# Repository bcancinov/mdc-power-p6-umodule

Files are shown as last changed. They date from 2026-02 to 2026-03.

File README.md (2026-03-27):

# mdc-power-p6-umodule
Modular Detector Controller Power 6V DC-DC uModule Mezzanine Module

## Overview
12V input to 6V output DC-DC module, 3A nominal output, used as one of the `mdc-power-*` bias rails.
Designed for 2.0 MHz sync operation.
Mezzanine module.

## Power Stage
- Controller: `LTM4653` (`U1`)
  - Integrated µModule regulator including controller, MOSFETs, inductor, and support components.
  - Low-EMI µModule architecture suited for sensitive instrumentation rails.
  - EN55022B compliant regulator family (meets Class B EMI limits for conducted and radiated emissions).
  - Wide input range suitable for 12V systems.
  - Constant-frequency current-mode control.
  - Power good indicator and programmable soft-start.
  - External sync capability.

## Files
- Schematic: `power_p6_umodule.pdf`
- Simulation: `sim/` (LTspice and LTpowerCAD files used for loop and transient checks)

## Board Dimensions
- 44.8 mm x 41.5 mm

## Board Stackup
- 4-layer PCB

## CAD
- Designed using KiCad 9.

## Interface
- Control pins: `EN` (enable) and `PG` / `~PGOOD` (power good).
- Connector: `LSHM-140-04.0-L-DV-A-N-K-TR` (Samtec LSHM series) mezzanine for power and control signals.
  - Common pinout is shared across the 16V, -16V, 6V, and 3.3V variants.
  - Unused output rails are tied to GND on the specific module variant.

## Images
Layout:
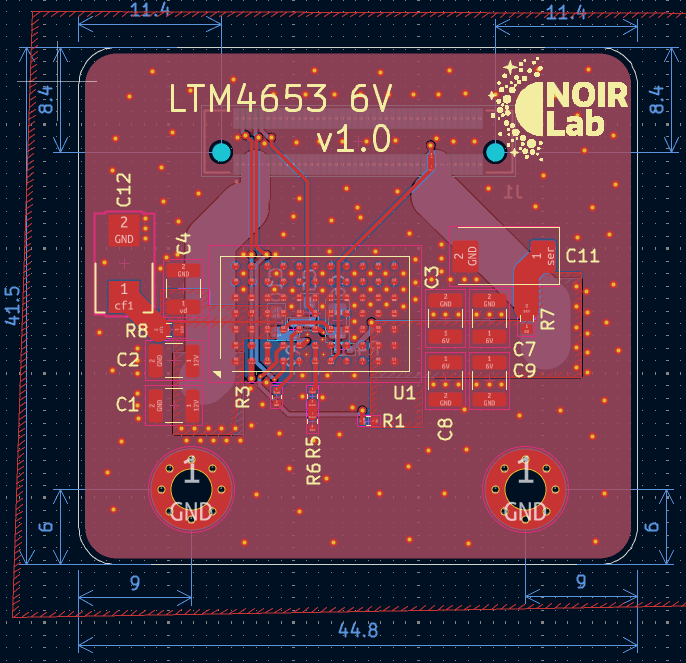
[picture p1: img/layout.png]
Layout


3D view:
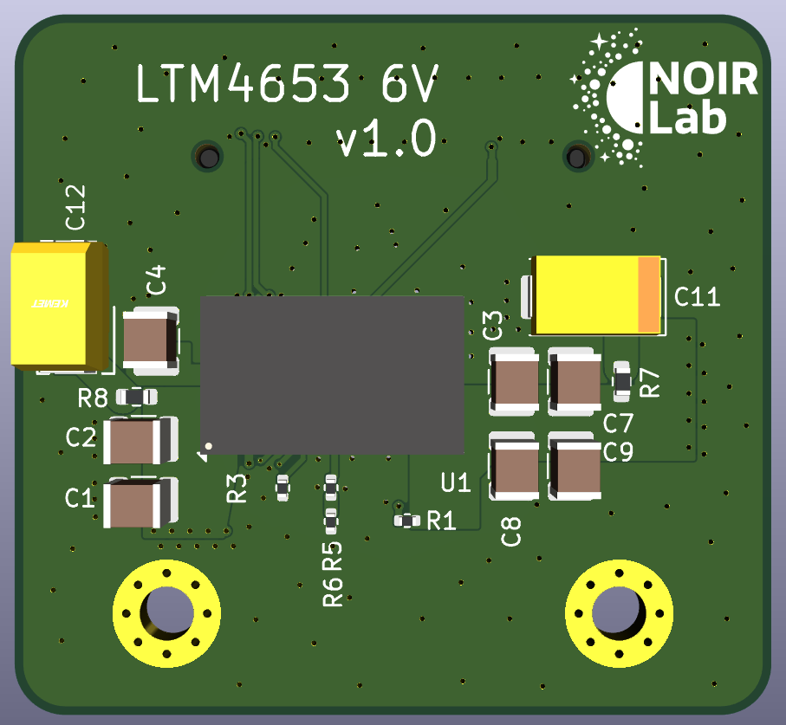
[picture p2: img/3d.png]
3D view


## License

This hardware design is licensed under the **Creative Commons Attribution-NonCommercial-ShareAlike 4.0 International License** (CC BY-NC-SA 4.0).

You are free to download, modify, and build upon this design for your own research or personal use, provided you give appropriate credit and share your modifications under the exact same license. **Commercial manufacturing or use of these designs is strictly prohibited without explicit permission.**

To view a copy of this license, visit [http://creativecommons.org/licenses/by-nc-sa/4.0/](http://creativecommons.org/licenses/by-nc-sa/4.0/) or see the `LICENSE` file in this repository.

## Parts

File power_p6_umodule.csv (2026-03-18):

Reference | Qty | M | MPN | Description
C1,C2,C4 | 3 | Murata | GRM32ER71K475KE14L | 4.7 µF ±10% 80V Ceramic Capacitor X7R 1210 (3225 Metric)
C3,C7,C8,C9 | 4 | TAIYO YUDEN | TMK325ABJ476MM-P | 47 µF ±20% 25V Ceramic Capacitor X5R 1210 (3225 Metric)
C5 | 1 | Murata | GRT1885C1E103FA02D | 10000 pF ±1% 25V Ceramic Capacitor C0G, NP0 0603 (1608 Metric)
C6 | 1 | Murata | GCM21BR71H105KA03L | 1 µF ±10% 50V Ceramic Capacitor X7R 0805 (2012 Metric)
C10 | 1 | Murata | GCM1885C2A100FA16D | 10 pF ±1% 100V Ceramic Capacitor C0G, NP0 0603 (1608 Metric)
C11 | 1 | KEMET | T521V226M025ATE040 | 22 µF Molded Tantalum Polymer Capacitor 25 V 2917 (7343 Metric) 40mOhm @ 100kHz
C12 | 1 | Kemet | T521X107M025ATE060 | 100 µF Molded Tantalum Polymer Capacitor 25 V 2917 (7343 Metric) 60mOhm @ 100kHz
H1,H2,NT1 | 3 |  |  | Mounting Hole with connection,Net tie, 2 pins
J1 | 1 | Samtec | LSHM-140-04.0-L-DV-A-N-K-TR | 80 Position Connector Self Mating, Non-Gendered, Hermaphroditic Surface Mount Gold
R1 | 1 | Vishay | CRCW040244K2FKED | 44.2 kOhms ±1% 0.1W, 1/10W Chip Resistor 0402 (1005 Metric) Automotive AEC-Q200 Thick Film
R2 | 1 | Vishay | CRCW04028K87FKED | 8.87 kOhms ±1% 0.1W, 1/10W Chip Resistor 0402 (1005 Metric) Automotive AEC-Q200 Thick Film
R3 | 1 | Vishay | CRCW040261K9FKED | Resistor, small symbol
R4 | 1 | Vishay | CRCW040224R0FKED | 24 Ohms ±1% 0.1W, 1/10W Chip Resistor 0402 (1005 Metric) Automotive AEC-Q200 Thick Film
R5 | 1 | Yageo | MCS04020C1203FE000 | 120 kOhms ±1% 0.063W, 1/16W Chip Resistor 0402 (1005 Metric) Anti-Sulfur Thin Film
R7,R8 | 2 | Vishay | RCWE0603R500FKEA | 500 mOhms ±1% 0.2W, 1/5W Chip Resistor 0603 (1608 Metric) Automotive AEC-Q200, Current Sense, Moisture Resistant Thick Film
U1 | 1 | Analog | LTM4653EY#PBF | Non-Isolated PoL Module DC DC Converter 1 Output 0.5 ~ 54.5V 4A 3.1V - 58V Input

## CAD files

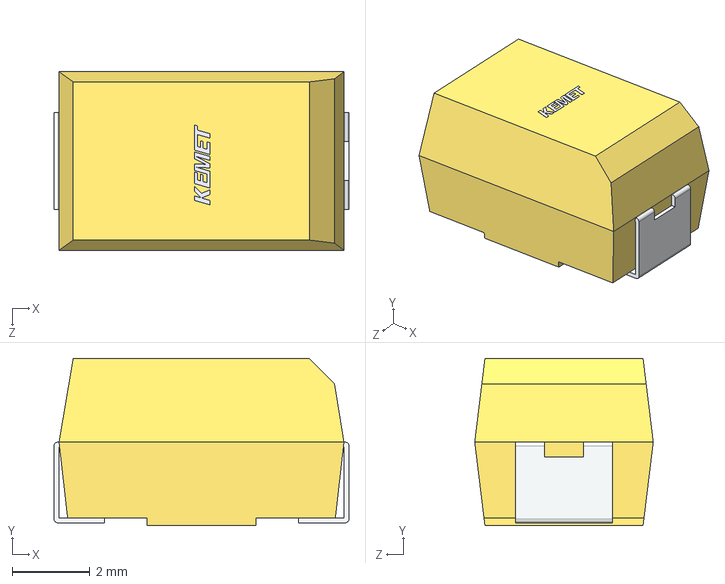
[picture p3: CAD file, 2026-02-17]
step/T521X.step
7.60 x 4.30 x 4.60 mm

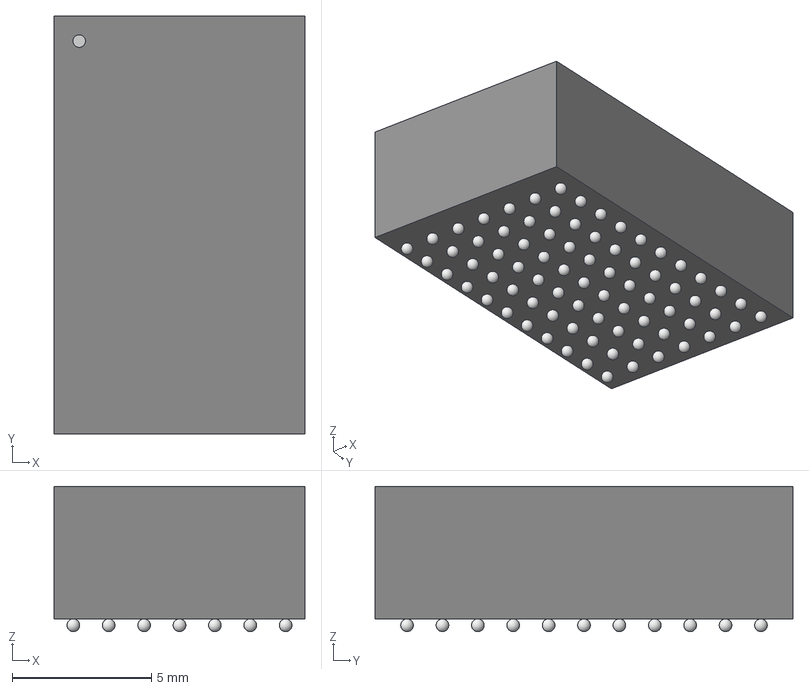
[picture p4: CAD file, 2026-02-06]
step/BGA77.step
9.00 x 15.0 x 5.21 mm

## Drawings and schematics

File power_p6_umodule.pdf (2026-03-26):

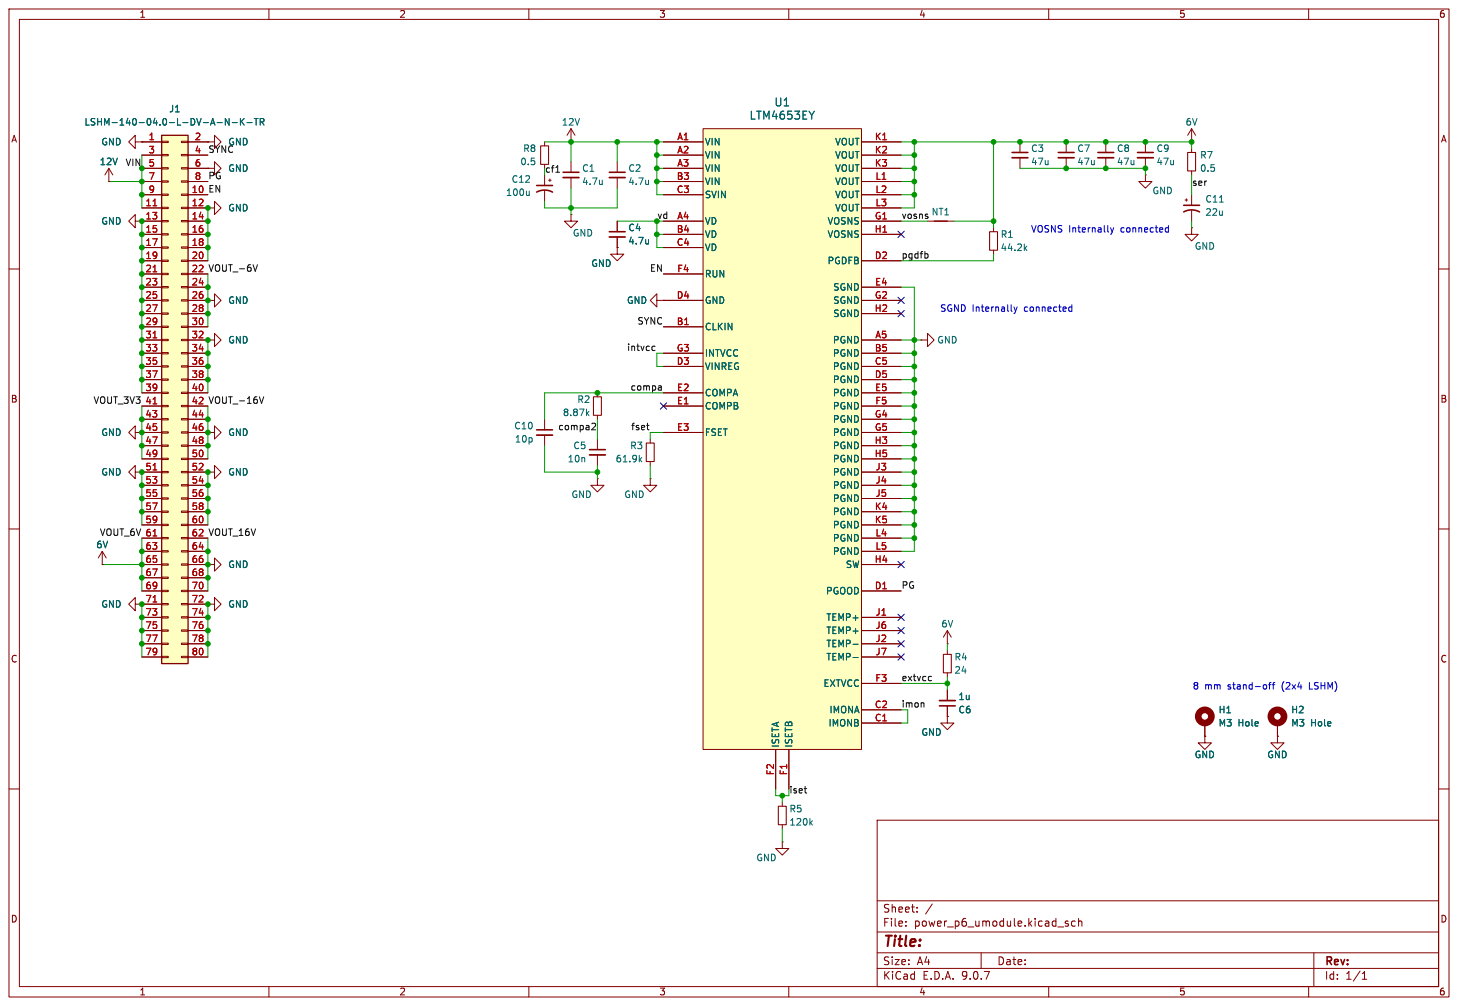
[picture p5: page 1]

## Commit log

2026-02-17 Add input RC snubber
    [T521X.step, power_p6_umodule.csv, power_p6_umodule.kicad_pcb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]
2026-03-18 update set resistor to thin film.
    [power_p6_umodule.csv, power_p6_umodule.kicad_pcb, power_p6_umodule.kicad_sch]
